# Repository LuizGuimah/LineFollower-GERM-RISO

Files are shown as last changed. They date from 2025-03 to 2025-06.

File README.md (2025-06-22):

# HERMES Line Follower - RISO/GERM/UDESC

This project was developed by a group of electrical engineering and computer science students with the goal of creating a high-performance line-following robot using PID control.

## Overview

The line-following robot is designed to detect and follow tracks with high precision. It uses reflectance sensors to monitor the line and dynamically adjust its position, ensuring efficient and fast movement.

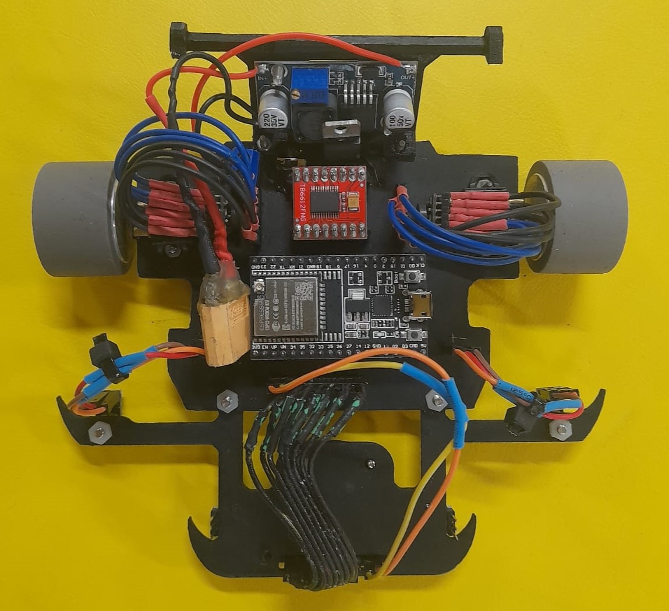
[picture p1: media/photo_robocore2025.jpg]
Robot photo


## Hardware Used

| Component | Description |
|---|---|
| **Microcontroller** | ESP32-WROOM |
| **Line Sensors** | Pololu QTR-8RC sensor array |
| **Lateral Sensors** | Two QRE sensors from ROBOCORE |
| **Motor Driver** | TB6612FN |
| **Motors** | Pololu N20 10,000 RPM motors with 1:10 gearbox |
| **Encoders** | Pololu encoders |
| **Voltage Booster** | XL6009 Boost Step Up |

## Esp32 Used Pinout

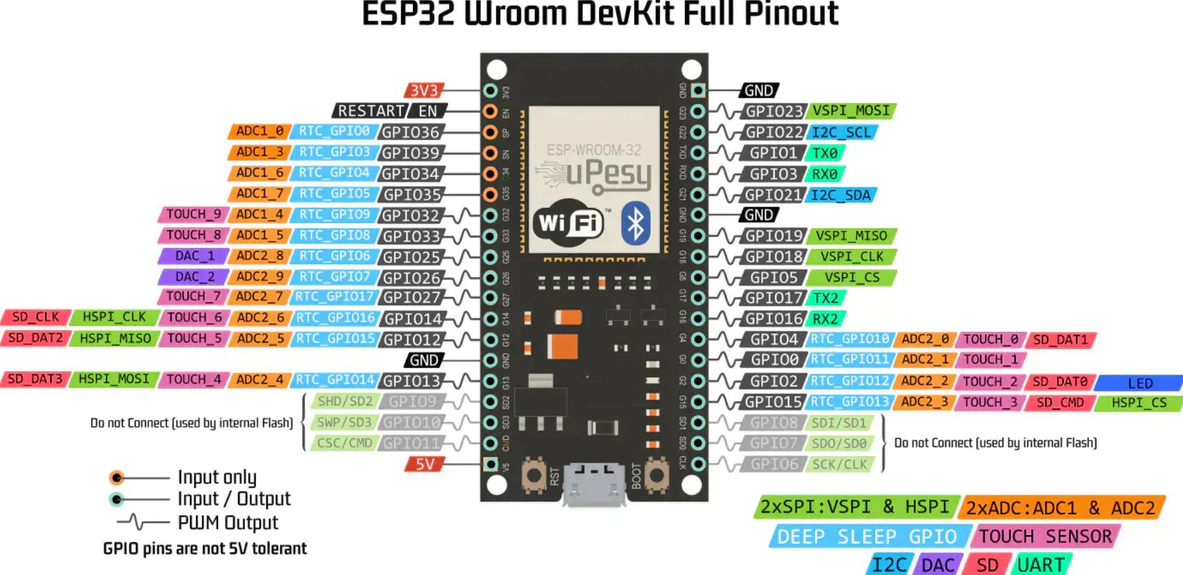
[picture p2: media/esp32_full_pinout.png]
esp32 photo


## Software and Control

The robot's control is based on a PID (Proportional, Integral, and Derivative) algorithm, which adjusts the motor speed according to the data provided by the line sensors. PID ensures the robot remains stable on the track, correcting its position in real-time.

## Inputs/Outputs

Line Sensors (QTR-8RC): Return values between 0 and 4095, where 0 indicates a white surface and 4095 indicates no reflectance.

Lateral Sensors (TCRT5000): Provide four digital inputs: 0 indicates "On Line," and 1 indicates "Off Line."

Encoders: Allow speed measurement of the motors and provide feedback for dynamic PID adjustments.

PWM to Motors: Speed control is achieved through PWM signals sent to the TB6612FN H-Bridge, allowing fine adjustments of speed and direction.

## PID Tuning

Tuning the PID parameters (Kp: Proportional, Ki: Integral, Kd: Derivative) is essential for the robot's performance. Here are some guidelines:

Adjust Kp: Increase until the robot oscillates around the line.

Adjust Kd: Add a value to reduce oscillations.

Adjust Ki: Small values can help correct systematic deviations.

## Melhorias pós-Robocore 2025

* Modularizar os sensores da frente dianteiros com 8 sensores de reflectância QRE da robocore, disponível em: [Sensor QRE Robocore](https://www.robocore.net/sensor-robo/sensor-de-linha-qre-analogico/com-barra-soldada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)

* Alterar os Pneus de borracha para o modelo StickyMAX S20 (Necessita de muito teste), disponível em: [Roda S20 macia Robocore](https://www.robocore.net/roda/roda-stickymax-s20-22mm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)

* Trocar e anexar diretamente na placa os encoders dos motores para melhorar a fiação do robo;

* Adquirir novos esps com melhor conexão WIRELESS (Na competição o bluetooth e o BLE não funcionam com perfeição no modelo padrão do ESP32 que estamos usando);

* Adquirir/trocar a bateria por uma de menor peso e melhor eficência (A tamandutech, a omega e a Raiju usam baterias de 300mAh);

* Melhorar a conexão da bateria com a placa (O jeito atual fica pegando levemente na roda);

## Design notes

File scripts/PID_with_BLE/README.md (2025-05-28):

# Controle de Robô Seguidor de Linha Hermes via BLE

Este projeto consiste em um robô seguidor de linha baseado em ESP32 (Hermes) controlado remotamente por uma aplicação Python com interface gráfica via Bluetooth Low Energy (BLE).

## Visão Geral

O sistema é dividido em duas partes principais:

1.  **`hermesBLE/`**: Contém o firmware Arduino (`.ino`) para o microcontrolador ESP32.
    *   Responsável pela lógica de baixo nível do robô:
        *   Leitura dos sensores de linha e laterais.
        *   Controle dos motores utilizando um driver (ex: L298N ou similar).
        *   Implementação de um controlador PID para seguir a linha.
        *   Máquina de estados para gerenciar diferentes comportamentos do robô (seguir linha, parar, manobras em curvas/marcações).
        *   Servidor BLE para comunicação com a aplicação Python:
            *   Recebe comandos para alterar o estado do robô (Iniciar/Parar).
            *   Recebe comandos para ajustar os parâmetros do PID (Kp, Ki, Kd) e a velocidade base (Bs) em tempo real.
            *   Envia o estado atual do robô (Parado, Seguindo Linha, etc.) para a interface Python via notificações BLE.

2.  **`controlePythonBLE/`**: Contém a aplicação desktop em Python com interface gráfica (`customtkinter`).
    *   Permite ao usuário:
        *   Escanear e conectar-se ao robô Hermes via BLE.
        *   Iniciar e parar o movimento do robô.
        *   Ajustar os parâmetros do PID (Kp, Ki, Kd) e a velocidade base (Bs) através de sliders e campos de entrada.
        *   Enviar os parâmetros ajustados para o ESP32 em tempo real (modo automático) ou manualmente.
        *   Visualizar o estado atual do robô recebido do ESP32.
        *   Ver logs de comunicação e status.

## Funcionalidades

### Firmware ESP32 (`hermesBLE.ino`)
*   Comunicação BLE robusta com características para recepção (RX) e transmissão (TX) de dados.
*   Controle PID ajustável para seguir a linha.
*   Máquina de estados para diferentes fases da pista (ex: seguir linha, detectar marcações laterais).
*   Tratamento de perda de linha.
*   Notificação do estado atual do robô para o cliente BLE.
*   Parsing de comandos recebidos via BLE para atualização de Kp, Ki, Kd, Velocidade Base e Estado.

### Aplicação Python (`controlePythonBLE.py`)
*   Interface gráfica amigável construída com `customtkinter`.
*   Conexão e desconexão BLE com o ESP32.
*   Controles interativos (sliders e campos de texto) para ajuste dos parâmetros:
    *   `Kp`: Ganho Proporcional
    *   `Ki`: Ganho Integral
    *   `Kd`: Ganho Derivativo
    *   `Bs`: Velocidade Base dos motores
*   Botões para "Iniciar Robô" e "Parar Robô".
*   Exibição do estado atual do robô (recebido via notificações BLE).
*   Opção de envio automático de parâmetros ao modificar os sliders/campos ou envio manual.
*   Janela de log para depuração e feedback.

## Requisitos e Configuração

### Para o Firmware do ESP32 (`hermesBLE/`)

1.  **Hardware:**
    *   Microcontrolador ESP32.
    *   Sensores de linha.
    *   Sensores laterais.
    *   Driver de motor.
    *   Motores DC com rodas.
    *   Fonte de alimentação adequada.
2.  **Software (Arduino IDE):**
    *   Arduino IDE instalado.
    *   Suporte à placa ESP32 instalado na Arduino IDE (via Gerenciador de Placas).
    *   Bibliotecas Arduino necessárias (geralmente a biblioteca BLE nativa do ESP32 core já é suficiente, como `BLEDevice.h`).
3.  **Procedimento:**
    *   Abra o arquivo `hermesBLE/hermesBLE.ino` na Arduino IDE.
    *   Selecione a placa ESP32 correta e a porta COM.
    *   Compile e carregue o firmware no ESP32.
    *   Após carregar, o ESP32 deve começar a anunciar-se como "Hermes_BLE".

### Para a Aplicação Python (`controlePythonBLE/`)

1.  **Python:**
    *   Python 3.8 ou superior recomendado.
2.  **Bluetooth:**
    *   Um adaptador Bluetooth no seu computador que suporte BLE (Bluetooth 4.0+).
    *   O driver Bluetooth do seu sistema operacional deve estar funcionando corretamente.
3.  **Dependências Python:**
    *   `customtkinter`: Para a interface gráfica.
    *   `bleak`: Para a comunicação BLE.

4.  **Instalação das Dependências:**

    *   **Clone o repositório (se ainda não o fez):**
        ```bash
        git clone <URL_DO_SEU_REPOSITORIO>
        cd <NOME_DA_PASTA_DO_REPOSITORIO>
        ```

    *   **Navegue até a pasta da aplicação Python:**
        ```bash
        cd controlePythonBLE
        ```

    *   **(Opcional, mas recomendado) Crie e ative um ambiente virtual:**
        *   No Linux/macOS:
            ```bash
            python3 -m venv venv
            source venv/bin/activate
            ```
        *   No Windows:
            ```bash
            python -m venv venv
            .\venv\Scripts\activate
            ```

    *   **Instale as bibliotecas necessárias usando pip:**
        ```bash
        pip install customtkinter bleak
        ```
        *Nota: Em alguns sistemas Linux, pode ser necessário instalar pacotes adicionais para o `bleak` funcionar corretamente, como `libglib2.0-dev` e `bluez`.*
        ```bash
        # Exemplo para sistemas baseados em Debian/Ubuntu:
        # sudo apt-get update
        # sudo apt-get install libglib2.0-dev libdbus-1-dev bluez
        ```

## Como Executar

1.  **Ligue o Robô Hermes:** Certifique-se de que o ESP32 com o firmware `hermesBLE.ino` carregado esteja alimentado e funcionando. Ele deve estar anunciando via BLE.
2.  **Execute a Aplicação Python:**
    *   Abra um terminal ou prompt de comando.
    *   Navegue até o diretório `controlePythonBLE/` (e ative o ambiente virtual, se estiver usando um).
    *   Execute o script Python:
        ```bash
        python controlePythonBLE.py
        ```
3.  **Use a Interface:**
    *   Na interface gráfica, clique no botão **"Conectar"**. A aplicação irá procurar pelo dispositivo "Hermes_BLE".
    *   O status da conexão será exibido.
    *   Uma vez conectado, os controles (sliders, botões de iniciar/parar) serão habilitados.
    *   Você poderá ver o "Estado Robô" atualizado conforme ele é enviado pelo ESP32.
    *   Ajuste os parâmetros Kp, Ki, Kd, Bs. Se o "Envio Automático Parâmetros" estiver ligado, eles serão enviados ao ESP32 conforme você os altera (se o robô estiver iniciado). Caso contrário, clique em "Enviar Parâmetros Agora".
    *   Use "Iniciar Robô" para fazer o robô começar a seguir a linha (Estado 0) e "Parar Robô" para interrompê-lo (Estado 4).
    *   Para desconectar, clique em "Desconectar".

## Observações e Solução de Problemas

*   **Permissões Bluetooth:** Em alguns sistemas operacionais (especialmente Linux), sua aplicação Python pode precisar de permissões para acessar o hardware Bluetooth.
*   **Descoberta BLE:** A descoberta de dispositivos BLE pode, às vezes, ser instável. Se o "Hermes_BLE" não for encontrado:
    *   Verifique se o Bluetooth do seu computador está ligado.
    *   Verifique se o robô está ligado e dentro do alcance.
    *   Tente reiniciar o Bluetooth do computador ou o próprio robô.
    *   Verifique os logs na interface para mensagens de erro.
*   **Compatibilidade `bleak`:** `bleak` depende do backend BLE do sistema operacional. Certifique-se de que seu sistema está atualizado.

---

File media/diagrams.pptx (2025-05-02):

## Seguidor de linha

GERM/RISO

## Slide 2

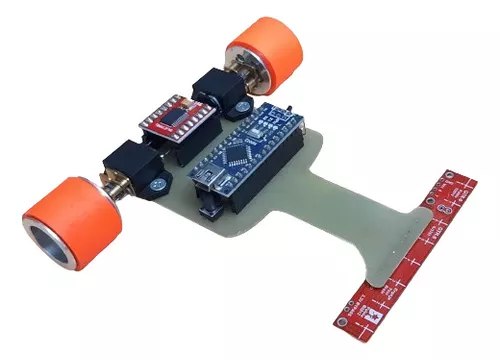
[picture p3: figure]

Robô diferencial

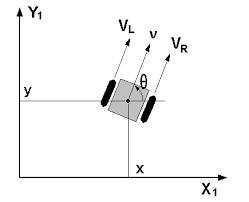
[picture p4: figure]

Sensor frontal

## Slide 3

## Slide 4

150

150

4095

4095

3500

3500

4095

4095

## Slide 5

150

4095

4095

3800

4095

200

300

3800

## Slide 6

Suavização

Δt=1ms

0

4095

3500

150

150

4095

ΣS0

150

3500

3071

Média do cilco

4095

4095

3500

ΣS2

4095

4095

4095

3500

ΣS5

4095

3500

4095

ΣS6

150

4095

ΣS7

150

3500

4095

4095

Δt=1ms

150

ΣS3

150

ΣS4

Δt=1ms

ΣS1

4095

4095

3500

150

3500

4095

4095

3500

150

150

3500

4095

4095

Δt=1ms

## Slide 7

Cálculo do desvio

Algoritmo de controle

Δt=4ms

Representação do ciclo

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
Ciclo de leituras

n_leituras e Δt_leitura

Atuadores

Δt=6ms

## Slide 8

Caso 1

Caso 2

Algoritmo de controle

Cálculo do desvio

Algoritmo de controle

0

1,16

Posição = Soma_ponderada / Soma

Posição = Soma_ponderada / Soma

0

23680

23955

20635

Soma

Soma_ponderada

Soma_ponderada = Σ Si * Peso[i]
Soma = Σ Si

Soma

Peso
{-4, -3, -2, -1, 1, 2, 3, 4}

Soma_ponderada

Soma_ponderada = Σ Si * Peso[i]
Soma = Σ Si

4095

4095

3500

150

150

3500

4095

4095

3800

300

150

300

3800

4095

4095

4095

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
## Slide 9

Controle

Motor esquerdo

VelBase + Correção

Variáveis

p = posição
i = i + posição
d = posição-Lp
Lp = posição

Algoritmo de controle

Correção
=
kp*p + ki*i + kd*d

Posição

1,16

PID

VelBase - Correção

Motor direito

Constantes

kp = 10
ki = 1
kd = 30

## Melhorias

-Representação da posição - soma_ponderada/soma??
-Discretização - hoje entre cada de um ciclo de leitura há 1ms de intervalo, mas entre cada ciclo tem 6ms, entre cada leitura deveria ter um tempo constante, assim como entre cada resposta aos atuadores já existe intervalo de 10ms
-Método de suavização - média de n leituras é a melhor opção?

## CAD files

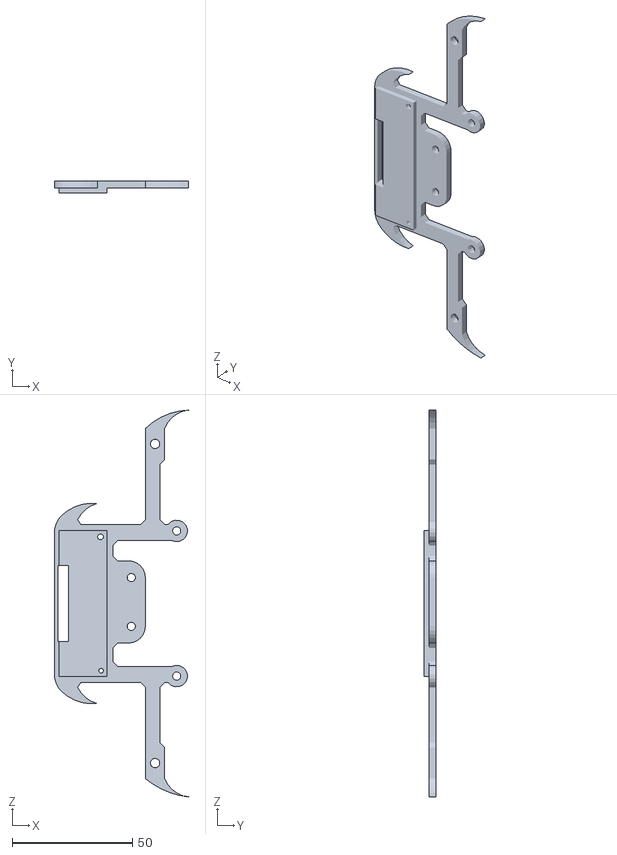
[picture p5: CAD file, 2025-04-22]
stl_parts/suporte_dianteiro.stl
56.0 x 5.00 x 161.2

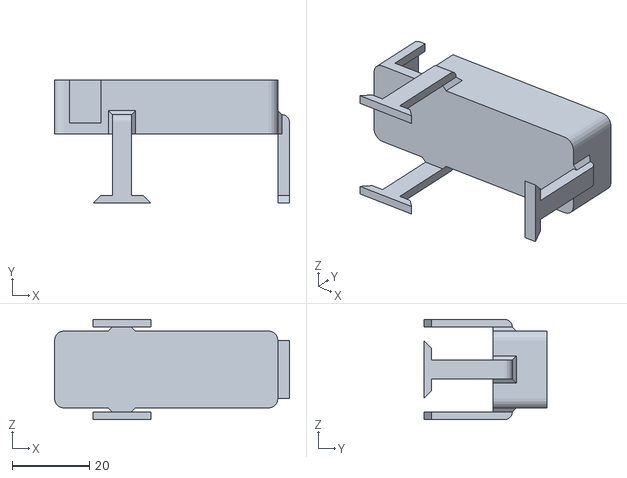
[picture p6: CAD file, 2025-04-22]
stl_parts/suporte_bateria.stl
61.0 x 32.0 x 26.0

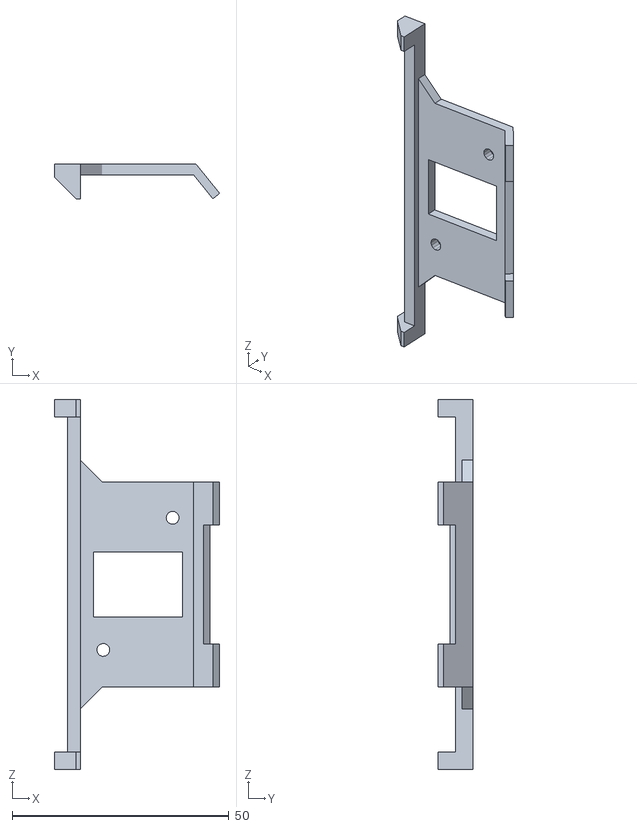
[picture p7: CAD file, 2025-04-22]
stl_parts/aerofoleo.stl
38.2 x 8.00 x 85.4

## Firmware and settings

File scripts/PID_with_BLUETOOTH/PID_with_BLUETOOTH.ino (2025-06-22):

#include <BluetoothSerial.h>

BluetoothSerial SerialBT;

#define PWMA 4 
#define AIN2 16
#define AIN1 17
#define STBY 5
#define BIN1 18
#define BIN2 19
#define PWMB 21

const unsigned int sensor[] = {35, 32, 33, 25, 26, 27}; // Sensores frontais para seguir linha
const int n_sensores = 6;
int pesos[] = {3, 2, 1, -1, -2, -3}; // Pesos para cálculo da posição

const unsigned int sensorLat[] = {13, 39}; // {Esquerdo, Direito}

int rspeed;
int lspeed;
float base_speed = 185; // Velocidade base dos motores
const int V_max = 255;

float Kp = 2.4;
float Ki = 0.002;
float Kd = 7;
float p, integral = 0, d, lp = 0; // Termos do PID (integral e lp precisam ser persistentes)
float error;                      // Erro atual (pos - sp)
float correction;                 // Correção calculada pelo PID
float sp = 0;                     // Setpoint (posição desejada, geralmente 0 para o centro da linha)

int sensor_read[n_sensores]; // Leituras brutas dos sensores de linha
long sensor_average = 0;     // Média ponderada das leituras (numerador)
int sensor_sum = 0;          // Soma das leituras (denominador)
int pos = 0;                 // Posição calculada da linha

int r_lat_read = 0;
int l_lat_read = 0;

int state = 0;                                    // Robô começa PARADO
int old_state_for_notification = -1;              // Para enviar notificação apenas quando o estado mudar
unsigned long last_state_send_time = 0;           // Para enviar estado periodicamente
const unsigned long state_send_interval = 1000;   // Intervalo para enviar estado (1 segundo)

unsigned long atual = 0;  // Timestamp para controle de tempo na máquina de estados
int aux = 0;              // Variável auxiliar para a lógica da máquina de estados

bool deviceConnected = false;
bool oldDeviceConnected = false;

int pid_calc();
void calc_turn();
void updatePIDConstants(String input);


void setup() {
  SerialBT.begin("LineFollower");
  Serial.begin(115200);
  for(int i=0; i<n_sensores; i++){
    pinMode(sensor[i], INPUT);
  }
  pinMode(sensorLat[0], INPUT);
  pinMode(sensorLat[1], INPUT);
  pinMode(STBY, OUTPUT);
  pinMode(PWMA, OUTPUT);
  pinMode(PWMB, OUTPUT);
  pinMode(AIN1, OUTPUT);
  pinMode(AIN2, OUTPUT);
  pinMode(BIN1, OUTPUT);
  pinMode(BIN2, OUTPUT);
  digitalWrite(STBY, HIGH);
  digitalWrite(AIN1, HIGH);
  digitalWrite(AIN2, LOW);
  digitalWrite(BIN1, HIGH);
  digitalWrite(BIN2, LOW); 
  analogWrite(PWMA, 0);
  analogWrite(PWMB, 0);
  
  sp = 0;
  atual = 0;
  integral = 0;
  lp = 0;

  while(!SerialBT.available()) {delay(10);}
  String input = SerialBT.readString();  // Read the incoming data as a string
  updatePIDConstants(input); 
}


void loop() {
  if (SerialBT.available()) {  // Check if Bluetooth data is available
    String input = SerialBT.readString();  // Read the incoming data as a string
    updatePIDConstants(input);  // Function to parse and update Kp, Ki, Kd
  }
  
  unsigned long currentTime = millis(); // Para envio periódico

    // --- LÓGICA PRINCIPAL DO ROBÔ ---
    r_lat_read = analogRead(sensorLat[1]) <= 3200; 
    l_lat_read = analogRead(sensorLat[0]) <= 3200;
    bool all_white = true; // Resetar a cada loop

   // int previous_state_for_debug = state; // Para debug de mudança de estado

     switch (state){
      case 0:
        calc_turn(); // Segue a linha
        if(r_lat_read){ 
          state++; 
        }
        tratarPerdaLinha();
        break;
      
      case 1:
        calc_turn(); // Continua seguindo a linha
        if (!r_lat_read){ 
          state++; 
        }
        tratarPerdaLinha();
        break;
      
      case 2:
        calc_turn(); // Continua seguindo a linha
        if (r_lat_read || l_lat_read){ 
          if(atual == 0){ 
            atual = millis(); 
          } 
        }
        if(atual != 0){ 
          if (millis() - atual >= 300){ 
            if(aux == 0){ 
              atual = 0; 
              state++; 
            } else { 
              aux = 0; 
              atual = 0; 
            } 
          } else { 
            if(l_lat_read){ 
              aux = 1; 
            } 
          } 
        }
        tratarPerdaLinha();
        break;

      case 3: // Saindo da curva/marcação
        calc_turn(); // Continua seguindo a linha
        if (!r_lat_read){ 
          state++; 
        }
        tratarPerdaLinha();
        break;
      
      case 4: // Estado de parada ou espera
        analogWrite(PWMA, 0);
        analogWrite(PWMB, 0);
        break;
    }  
  //delay(10);
}



void tratarPerdaLinha() {  // FUNÇÃO PARA TRATAR PERDA DE LINHA
    bool all_white = true;
    for(int i = 0; i < n_sensores; i++) {
        if(analogRead(sensor[i]) < 2000) { // Se algum sensor ler preto (valor baixo)
            all_white = false;
            break;
        }
    }

    if(all_white) {
        // Lógica: o robo deve virar para um lado para reencontrar a linha
///////////////////////////////////////////
        Serial.println(lp);
        float spinSpeed = base_speed + 30;
        if (spinSpeed>255) spinSpeed = 255;
        if(lp>0){
          while (analogRead(sensor[2]) >= 2000 && analogRead(sensor[3]) >= 2000) { // Timeout de 1.5s
              analogWrite(PWMA, 0);   
              analogWrite(PWMB, spinSpeed); 
              delay(10);
              Serial.println(lp);
          }
        }else{
          while (analogRead(sensor[2]) >= 2000 && analogRead(sensor[3]) >= 2000) { // Timeout de 1.5s
              analogWrite(PWMA, spinSpeed);   
              analogWrite(PWMB, 0); 
              delay(10);
              Serial.println(lp);
          }
        }
//////////////////////////////////////////////tentar com lp ao inves de correction
        // Após a tentativa, pode ser útil parar brevemente ou reavaliar antes de continuar o PID
        // analogWrite(PWMA, 0); // Opcional: Parar os motores após a tentativa
        // analogWrite(PWMB, 0);
        // delay(50);
    }
}


int pid_calc() {
  sensor_average = 0; 
  sensor_sum = 0;

  for(int i = 0; i < n_sensores; i++) {
    sensor_read[i] = analogRead(sensor[i]); 
    sensor_average += (long)sensor_read[i] * pesos[i] * 100; 
    sensor_sum += sensor_read[i];
  }

  if (sensor_sum == 0) {            // Todos os sensores leram algo que somou zero (ou todos leram valor mínimo)
    if (lp > 0) return Kp * 1000;   // Se o último erro 'p' (lp) era para a direita, continua virando forte para direita
    if (lp < 0) return Kp * -1000;  // Se o último erro 'p' (lp) era para a esquerda, continua virando forte para esquerda
    return 0;
  }

  pos = sensor_average / sensor_sum;

  error = pos - sp;
  p = error; 
  integral += p;
  
  float integral_max = 5000;
  float integral_min = -5000;
  integral = constrain(integral, integral_min, integral_max);
  
  d = p - lp;       
  lp = p;           

  return int(Kp * p + Ki * integral + Kd * d);
}

void calc_turn() {
 

/////////////////////////////////////////////////
  /*static unsigned long lastTime = 0;
  static int count = 0;
  
  count++;
  
  if (millis() - lastTime >= 1000) {  // Contagem por segundo
    Serial.print("Frequência PID: ");
    Serial.print(count);
    Serial.println(" Hz");
    count = 0;
    lastTime = millis();
  }
  */
/////////////////////////////////////////////////
  
  correction = pid_calc();
  
  // Se correction > 0, linha à direita, precisa virar à DIREITA: rspeed DIMINUI, lspeed AUMENTA
  // Se correction < 0, linha à esquerda, precisa virar à ESQUERDA: rspeed AUMENTA, lspeed DIMINUI
  rspeed = base_speed - correction; 
  lspeed = base_speed + correction;
  
  //BLOCO NOVO VOLKMAN-----------------------------------------------------------------------
  
  if (lspeed <= 0)                          //Inverte a rotação do motor para reduzir a velocidade mais rápido
  {
    lspeed = -lspeed;
    digitalWrite(BIN1, LOW);
    digitalWrite(BIN2, HIGH);
  }
  else
  {
    digitalWrite(BIN1, HIGH);
    digitalWrite(BIN2, LOW);
  }

  if (rspeed <= 0)                        //Inverte a rotação do motor para reduzir a velocidade mais rápido
  {
    rspeed = -rspeed;
    digitalWrite(AIN1, LOW);
    digitalWrite(AIN2, HIGH);
  }
  else
  {
    digitalWrite(AIN1, HIGH);
    digitalWrite(AIN2, LOW);
  }

  if (lspeed >= V_max)
  {
    lspeed = V_max;
    //    erro_I = erro_I - ((erro + erro_anterior) / 2) * t_loop;  //anti windup
  }
  if (rspeed >= V_max)
  {
    rspeed = V_max;
    //    erro_I = erro_I - ((erro + erro_anterior) / 2) * t_loop;  //anti windup
  }

  
  analogWrite(PWMA, rspeed);
  analogWrite(PWMB, lspeed); 
}

void updatePIDConstants(String input) {
  input.trim();
  int kpIndex = input.indexOf("Kp=");
  int kiIndex = input.indexOf("Ki=");
  int kdIndex = input.indexOf("Kd=");
  int speedIndex = input.indexOf("Speed=");
  
  if (kpIndex != -1 && kiIndex != -1 && kdIndex != -1 && speedIndex != -1) {
    String kpValue = input.substring(kpIndex + 3, input.indexOf(",", kpIndex));
    String kiValue = input.substring(kiIndex + 3, input.indexOf(",", kiIndex));
    String kdValue = input.substring(kdIndex + 3, input.indexOf(",", kdIndex));
    String speedValue = input.substring(speedIndex + 3);


    Kp = kpValue.toFloat();
    Ki = kiValue.toFloat();
    Kd = kdValue.toFloat();
    base_speed = speedValue.toFloat();

    SerialBT.print("Updated Kp: ");
    SerialBT.print(Kp);
    SerialBT.print(", Ki: ");
    SerialBT.print(Ki);
    SerialBT.print(", Kd: ");
    SerialBT.print(Kd);
    SerialBT.print(", Speed: ");
    SerialBT.println(base_speed);
  } else {
    SerialBT.println("Formato invalido! Esperado: Kp=0.5,Ki=0.0003,Kd=0.6,Speed=185");
  }
}

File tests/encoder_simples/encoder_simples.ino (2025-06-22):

#define ENCODER_A 23 // Pin for Encoder A
#define ENCODER_B 22 // Pin for Encoder B

#define ENCODER_C 15  // Pin for Encoder C
#define ENCODER_D 2 // Pin for Encoder D

volatile int encoder_value = 0; // Global variable for storing the encoder position
volatile int encoder_value2 = 0; // Global variable for storing the encoder position

void encoder_isr() {
  // Reading the current state of encoder A and B
  int A = digitalRead(ENCODER_A);
  int B = digitalRead(ENCODER_B);

  int C = digitalRead(ENCODER_C);
  int D = digitalRead(ENCODER_D);

  /*
  // If the state of A changed, it means the encoder has been rotated
  if ((A == HIGH) != (B == LOW)) {
    encoder_value--;
  } else {
    encoder_value++;
  }
  */

  // If the state of A changed, it means the encoder has been rotated
  if ((C == HIGH) != (D == LOW)) {
    encoder_value2--;
  } else {
    encoder_value2++;
  }

}

void setup() {
  Serial.begin(115200);
  pinMode(ENCODER_A, INPUT_PULLUP);
  pinMode(ENCODER_B, INPUT_PULLUP);
  pinMode(ENCODER_C, INPUT_PULLUP);
  pinMode(ENCODER_D, INPUT_PULLUP);

  // Attaching the ISR to encoder A
  //attachInterrupt(digitalPinToInterrupt(ENCODER_A), encoder_isr, CHANGE);
  attachInterrupt(digitalPinToInterrupt(ENCODER_C), encoder_isr, CHANGE);
}

void loop() {
  // Serial.println("Encoder1 value: " + String(encoder_value) + "  |  Encoder2 value: " + String(encoder_value2));
  Serial.println("Encoder2 value: " + String(encoder_value2));
}

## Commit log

2025-03-12 stl_parts UPDATE
    [seguidor2_0_HERMES.stl]
2025-04-03 Adjustments and primitive leave the curve case
2025-04-16 stl Updates
    [aerofoleo.stl, suporte_dianteiro_sensores.stl]
2025-04-22 stl UPDATE
    [aerofoleo.stl, seguidor2_0_HERMES.stl, suporte_bateria.stl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]
2025-06-22 encoders teste UPDATE
